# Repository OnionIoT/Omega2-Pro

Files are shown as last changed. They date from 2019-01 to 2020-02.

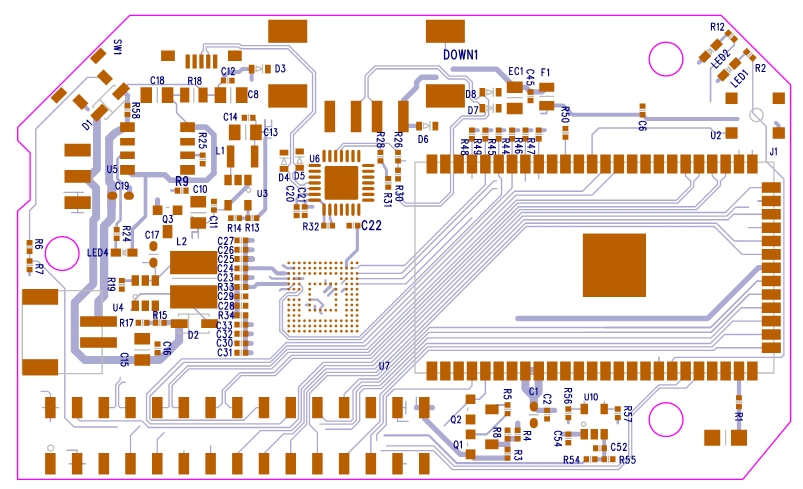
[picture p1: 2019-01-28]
Hardware/R1.2/Omega2-Pro-v1.2-Layout.jpg

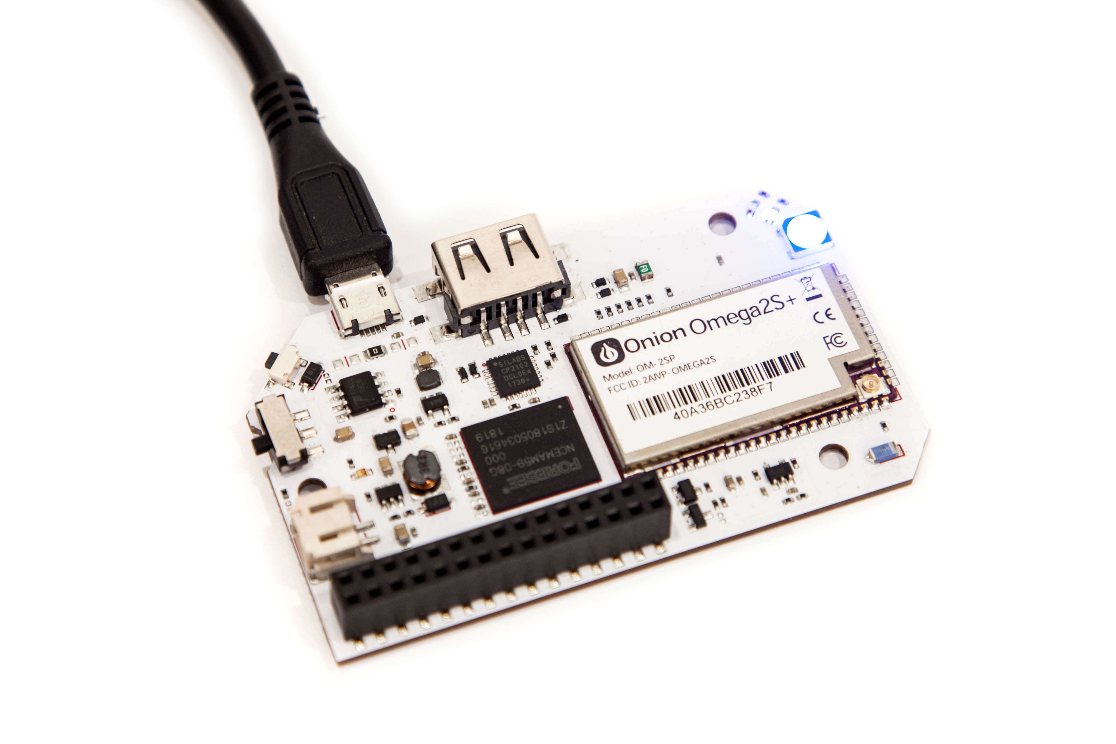
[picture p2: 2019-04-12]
Images/OM-O2PRO-5-led-1.jpg

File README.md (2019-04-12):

# Omega2-Pro
Onion Omega2 Pro IoT Computer

## Getting Started

Get your Omega2 Pro up and running by following the [Omega2 Pro getting started guide](https://onion.io/omega2-pro-get-started/). It also features details on [using your Omega2 Pro](https://onion.io/omega2-pro-get-started/#usingtheomega2pro).

## Images

The [Images](./Images) directory holds official photos of the Omega2 Pro. Credit goes to the team at [Crowd Supply](https://www.crowdsupply.com/).

## Hardware

Schematics and layout images are available for the Omega2 Pro

* R1.2
    * Date: Nov 26, 2018
    * Changes:
        * Small adjustment for power supply circuit

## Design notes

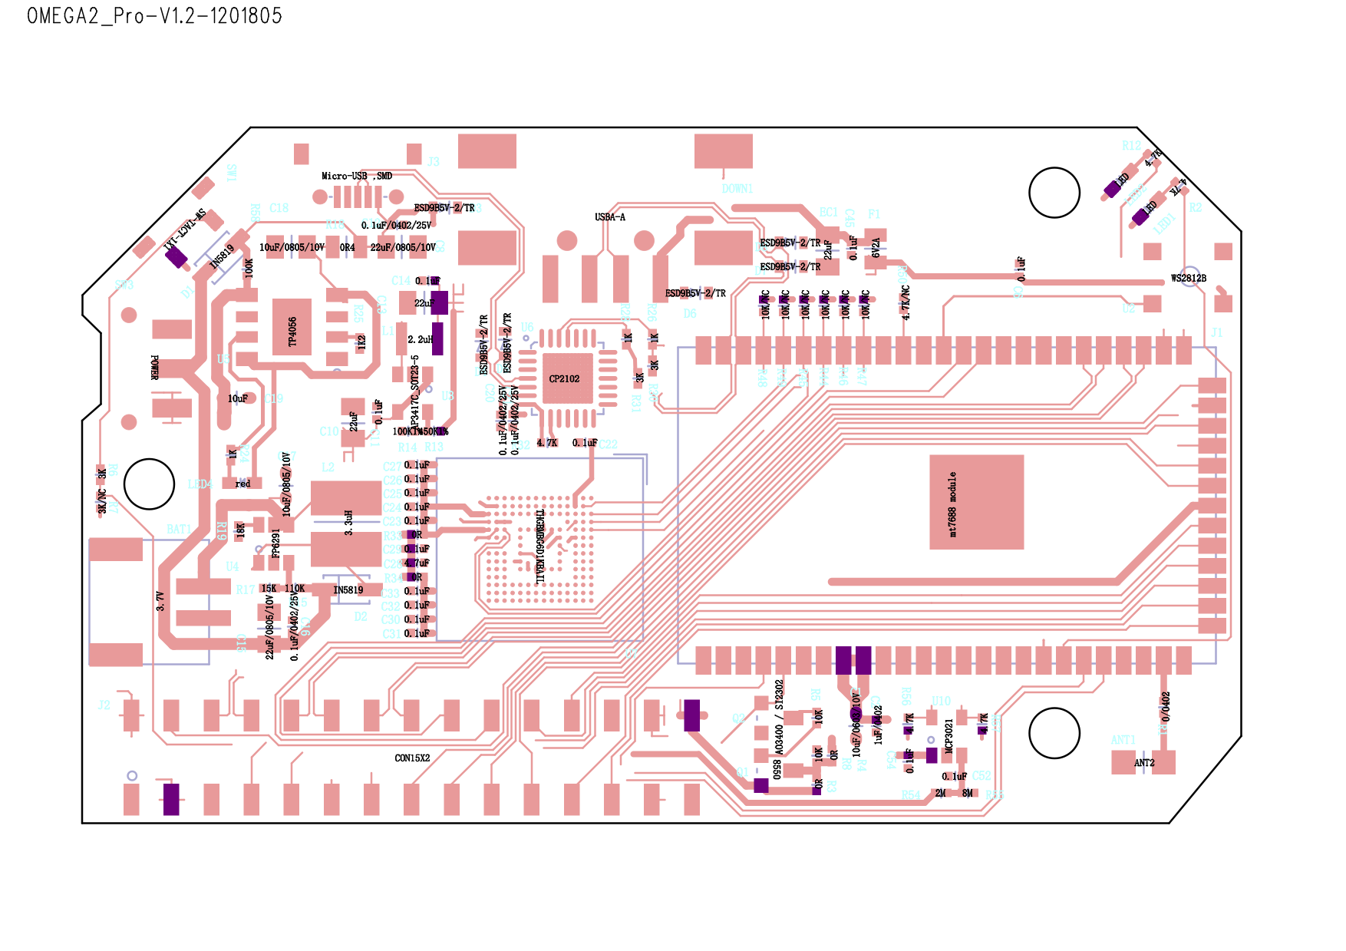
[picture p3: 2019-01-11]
Hardware/R1.1/Omega2-Pro-Layout.png

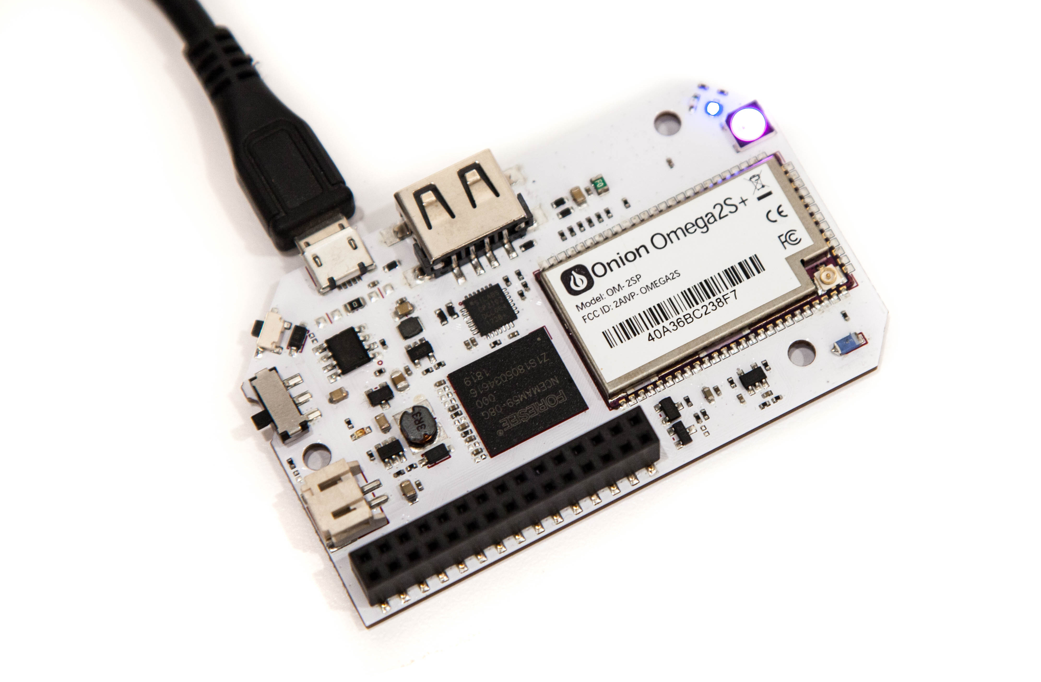
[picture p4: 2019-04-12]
Images/OM-O2PRO-5-led-3.jpg

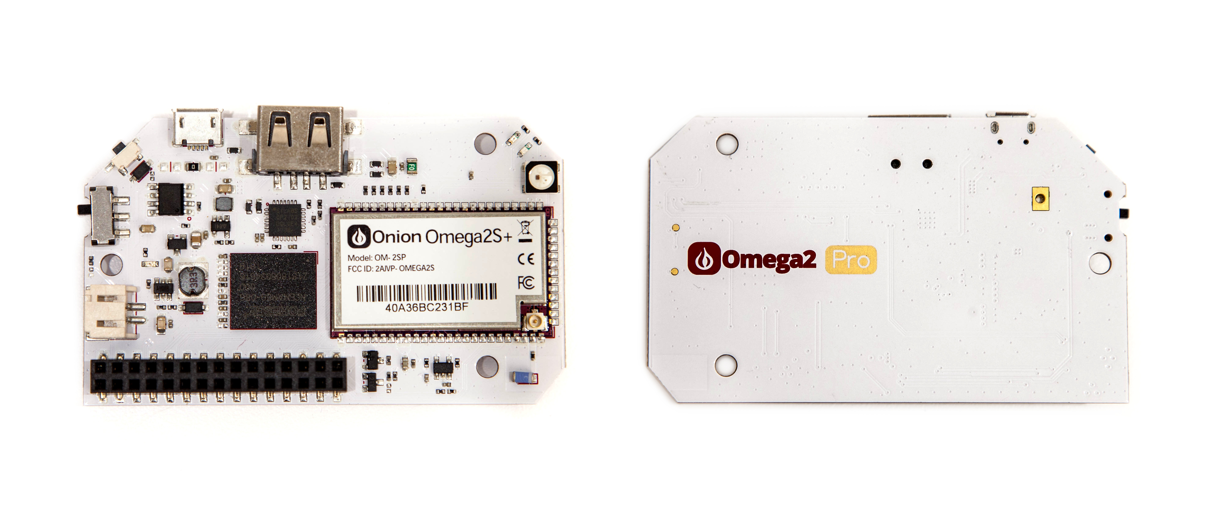
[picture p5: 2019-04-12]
Images/OM-O2PRO-3-side-by-side.jpg

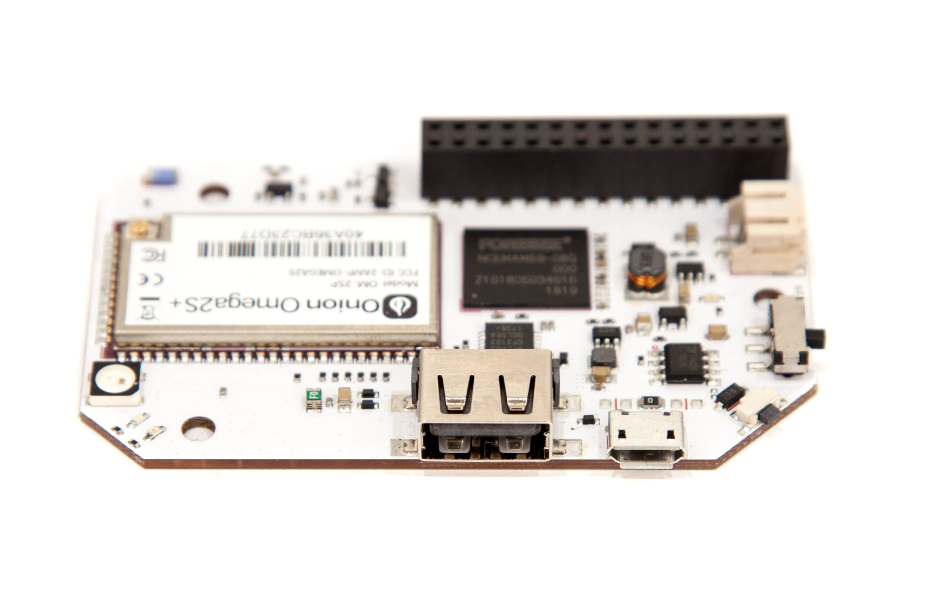
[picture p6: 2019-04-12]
Images/OM-O2PRO-2-side-1.jpg

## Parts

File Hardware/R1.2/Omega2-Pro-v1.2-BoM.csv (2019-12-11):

Index | Name | Qty | Decal | Value
1 | ANT1 | 1 | R1206 | RFANT3216120A5T
2 | BAT1 | 1 | PH_CON2-SMT | PH_CON2-SMT 2.0mm
3 | C1 | 1 | C0603 | 10uF/0603/10V
4 | C2 | 1 | C0402 | 1uF/0402
5 | C6,C11,C14,C22,C23,C27,C30,C33,C45,C52,C54 | 11 | C0402 | 0.1uF
6 | C15 | 1 | C1206 A type 3516 bile capacitor | 68uF 6.3V
 | C10 | 1 | C0805 | 47uF/0805/10V
7 | C12,C16,C20,C21 | 4 | C0402 | 0.1uF/0402/10V
8 | C17,C19,C13,EC1 | 5 | C0805 | 10uF/0805/10V
9 | C28 | 1 | C0402 | 4.7uF
10 | D1,D2 | 2 | SOD-123 | IN5819
11 | D3,D4,D5,D6,D7,D8 | 6 | SOD-523 | ESD5B5.0S
12 | DOWN1 | 1 | USB10/SMT | USB AF short body 10.0 full paste thickness 6.3 with straight edges
13 | F1 | 1 | R0805 | 6V1A
14 | J1 | 1 | Omega2SP | Omega2SP
15 | J2 | 1 | HEADER_2X15 | KONSON row female 2.54 * 7.1 2 * 15P SMT
16 | J3 | 1 | MICRO-USB-5PIN_1 | Micro 5.9 pitch USB socket
17 | L1 | 1 | IND-2520 current 1.2A or above | 2.2uH
18 | L2 | 1 | CD54 | 3.3uH
19 | LED1 | 1 | LED-0603 | LED-0603 Blue
20 | LED2 | 1 | LED-0603 | LED-0603 Orange
21 | LED4 | 1 | LED-0603 | LED-0603 Green
22 | Q1 | 1 | SOT23 | 8550
23 | Q2 | 1 | SOT23-2 | AO3400 / SI2302
24 | Q3 | 1 | SOT23 | AO3401
25 | R26 | 1 | R0402 | 2K
26 | R9,R2_R12,R32,R56,R57,R50,R24 | 8 | R0402 | 4.7K
27 | R1,R4,R33,R34 | 5 | R0402 | 0R
28 | R6,R30,R31 | 3 | R0402 | 3K
29 | R13 | 1 | R0402 | 450K1%
30 | R14 | 1 | R0402 | 100K1%
31 | R15 | 1 | R0402 | 110K
32 | R17 | 1 | R0402 | 15K
33 | R18 | 1 | R0805 | 0R
34 | R19 | 1 | R0402 | 18K
35 | R28 | 2 | R0402 | 1K
36 | R25 | 1 | R0402 | 1K2
37 | R44,R45,R46,R47,R48,R49,R5,R8 | 8 | R0402 | 10K
38 | R54 | 1 | R0402 | 2M
39 | R55 | 1 | R0402 | 8.2M
41 | SW1 | 1 | TACTILE_SWITCH_4 | SW-TACT-1X1 button
42 | SW3 | 1 | SLIDE_SWITCH_5 | POWER switch
43 | U2 | 1 | LED-PAD-4PIN | WS2812B
44 | U3 | 1 | SOT23-5 | AP3417C_SOT23-5
45 | U4 | 1 | SOT23-6 | FP6291
46 | U5 | 1 | SOP8-1_27 | TP4056 1A
47 | U6 | 1 | QFN28_6X6 | CP2102-GMR
48 | U7 | 1 | BGA153/SMD/P0.5/11.5*13mm 8G | eMMC5.1 8GB | Kinston EMMC08G-T227-A01, Sandisk SDINBDG4-8G, FORESEE NCEMAM59-08G
49 | U10 | 1 | SOT23-5 | MCP3021A5T
NC
1 | R7 | 1 | R0402 | 3K/NC
2 | C24,C25,C26,C31,C32,C29, | 6 | C0402 | 0.1uF
3 | R3 | 1 | R0402 | 0R
4 | C8,C18 | 2 | C0805 | 10uf
5 | R58 | 1 | R0402 | 100K

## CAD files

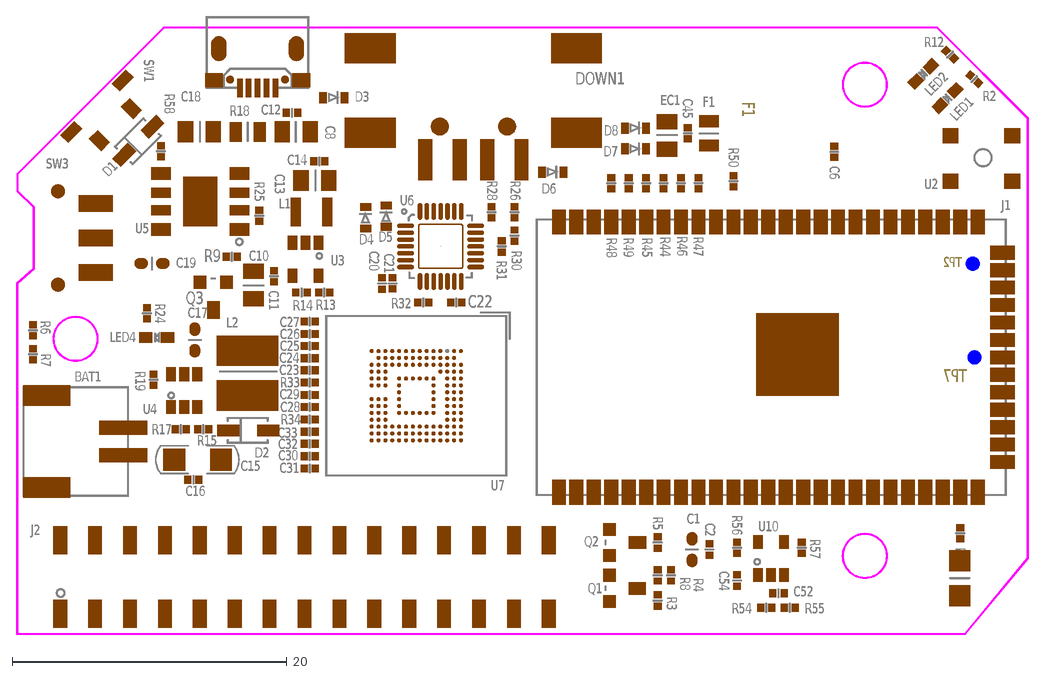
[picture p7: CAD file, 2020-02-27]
Hardware/R1.2/Omega2-Pro.dxf
BAT1
R19
LED4
R9
R55
R54
C19
U7
R6
R7
C22
C11
C12
C14
C16
C2
C20
C21
C23
C24
C25
C26
C27
C28
C29
C30
C31
C32
C33
C45
C52
C54
C6
C1
C17
C10
C13
C18
C8
EC1
L2
J2
L1
LED1
LED2
U2
R1
R12
R13
R14
R15
R17
R2
R24
R25
R26
R28
R3
R30
R31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

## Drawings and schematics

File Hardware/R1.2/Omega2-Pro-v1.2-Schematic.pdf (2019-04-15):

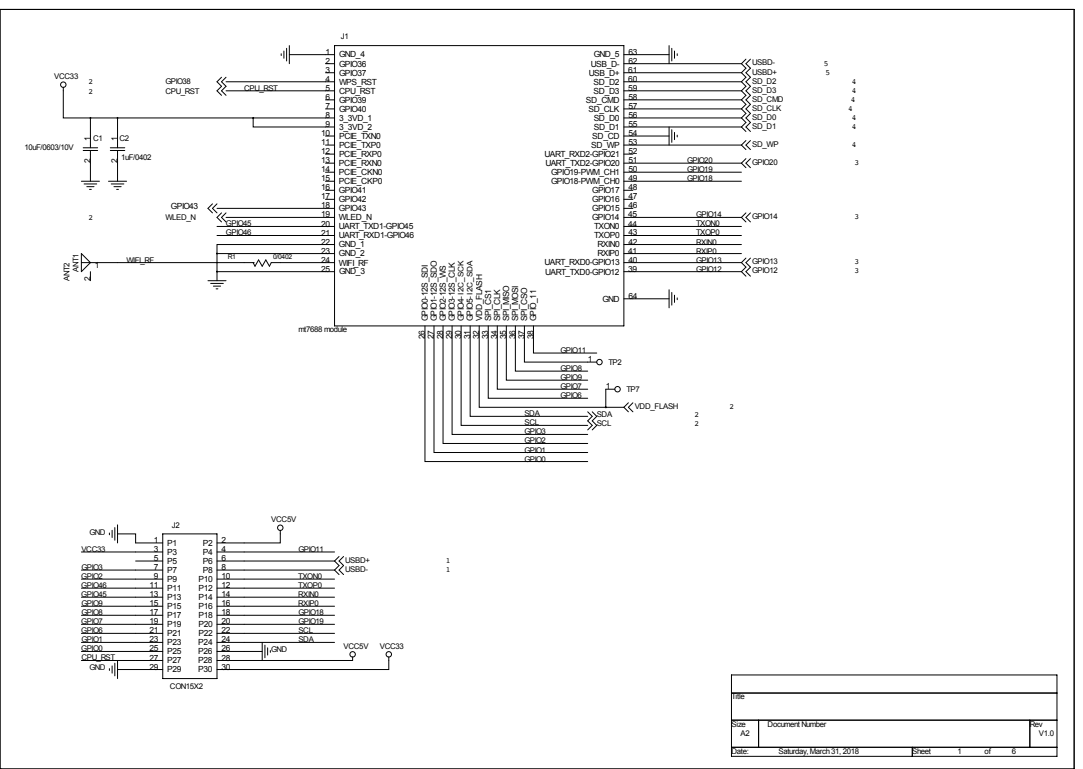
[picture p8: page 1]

Size A2 | Document Number | Rev V1.0

Date: Saturday, March31, 2018 | Sheet 1 of

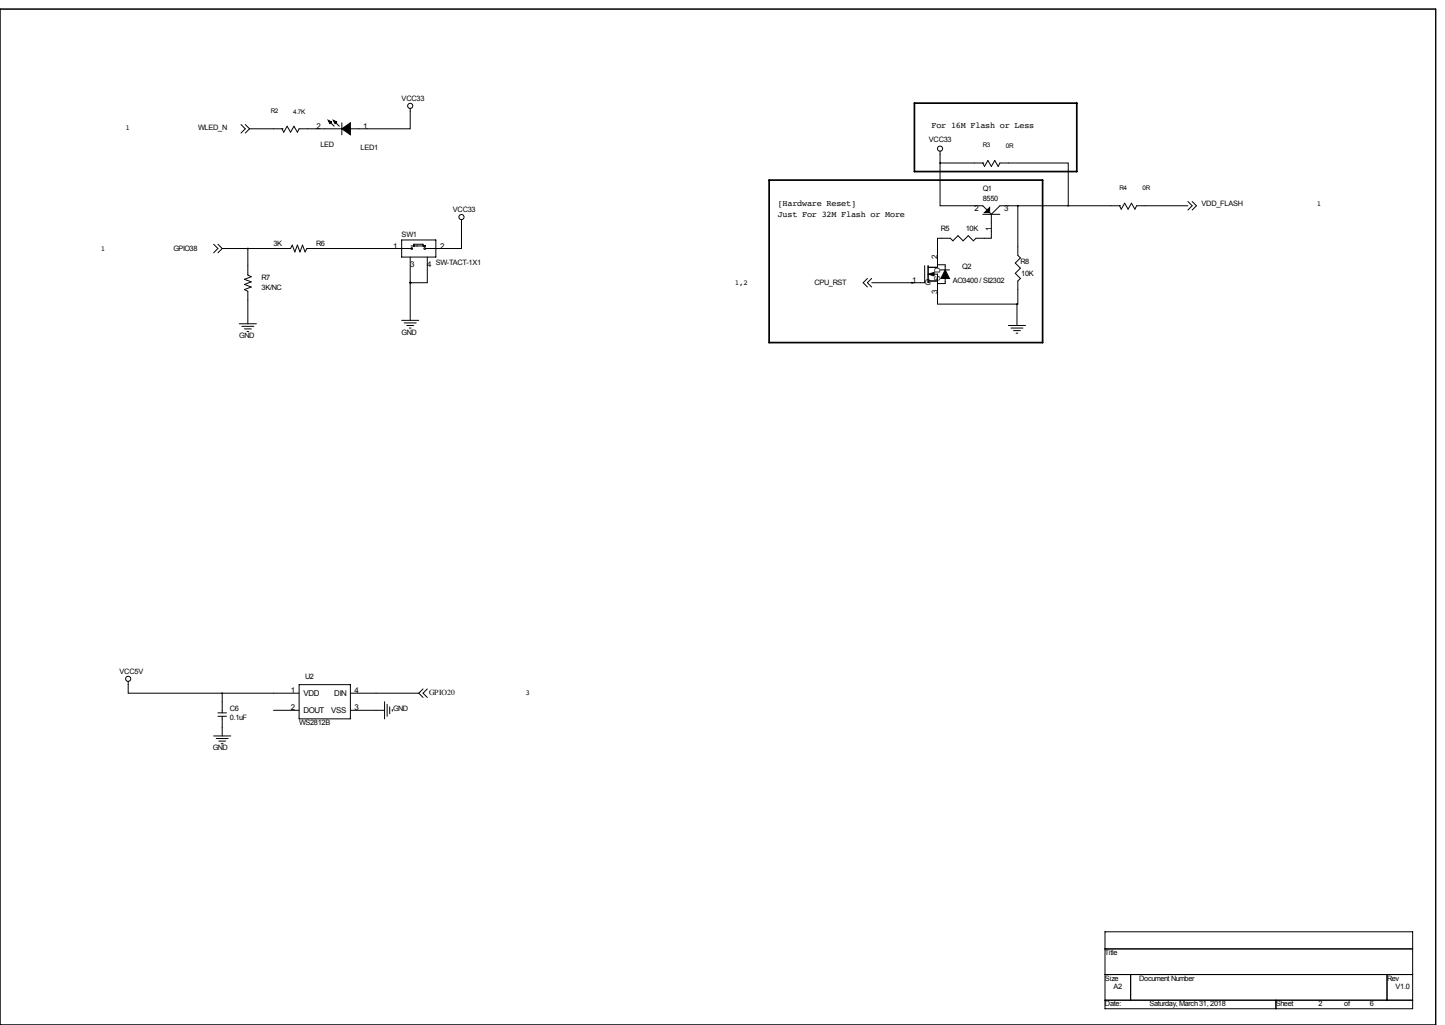
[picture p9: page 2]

[Hardware Reset]
Just For 32M Flash or More

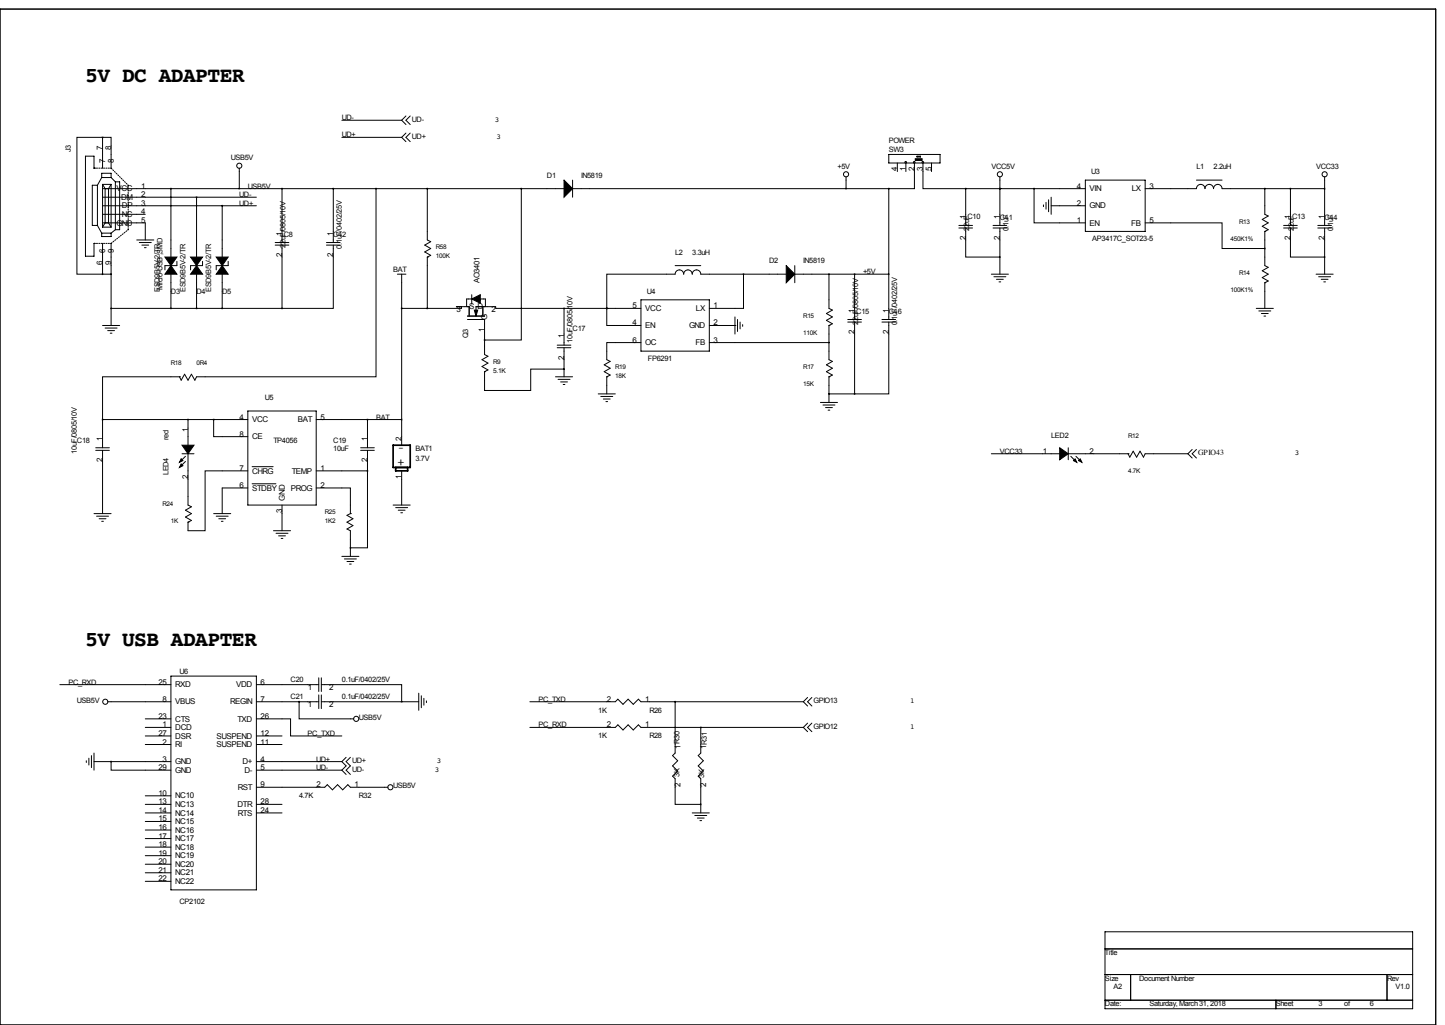
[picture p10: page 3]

DM 2 | UD- | | L2 3.3uH
DP 3 | | UD+
NC 4

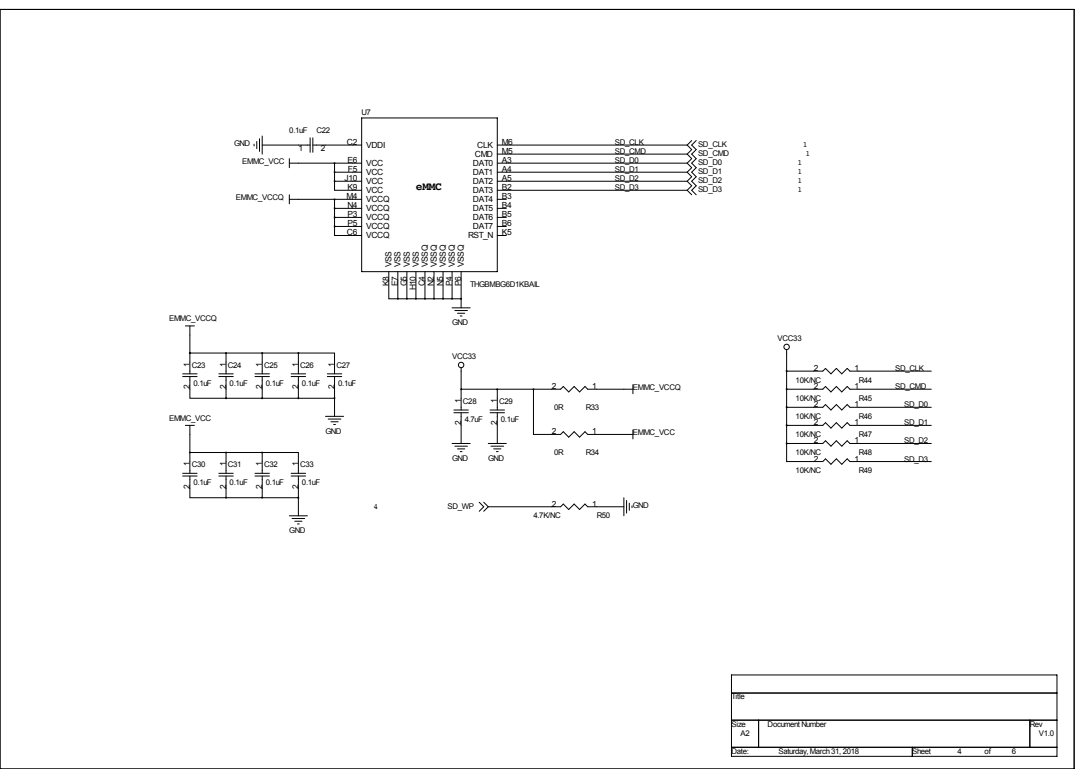
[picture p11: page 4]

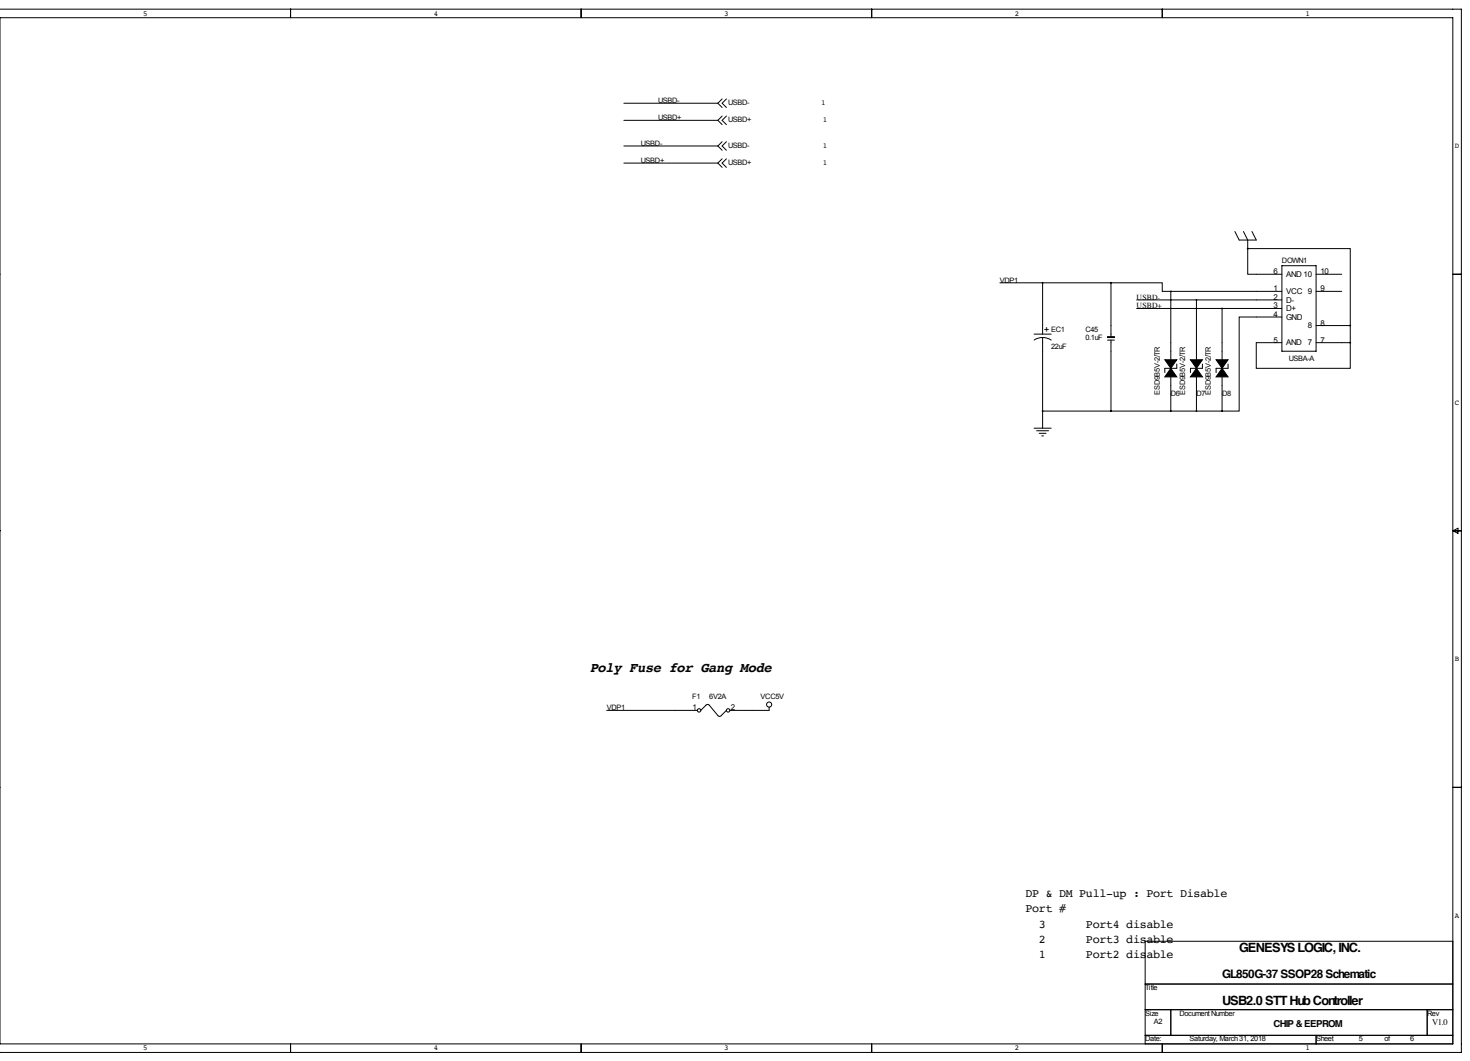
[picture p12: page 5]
GL850G-37 SSOP28 Schematic; Port4 disable; Port3 disable; Port2 disable; ESD9B5V-2/TR; AND; VCC; GND; DOWN1; USBA-A; VCC5V; USBD-; USBD+; VDP1

Poly Fuse for Gang Mode

DP & DM Pull-up : Port Disable
Port #

GENESYS LOGIC, INC.

USB2.0 STT Hub Controller

CHIP & EEPROM

Date: | Sheet 5 of 6

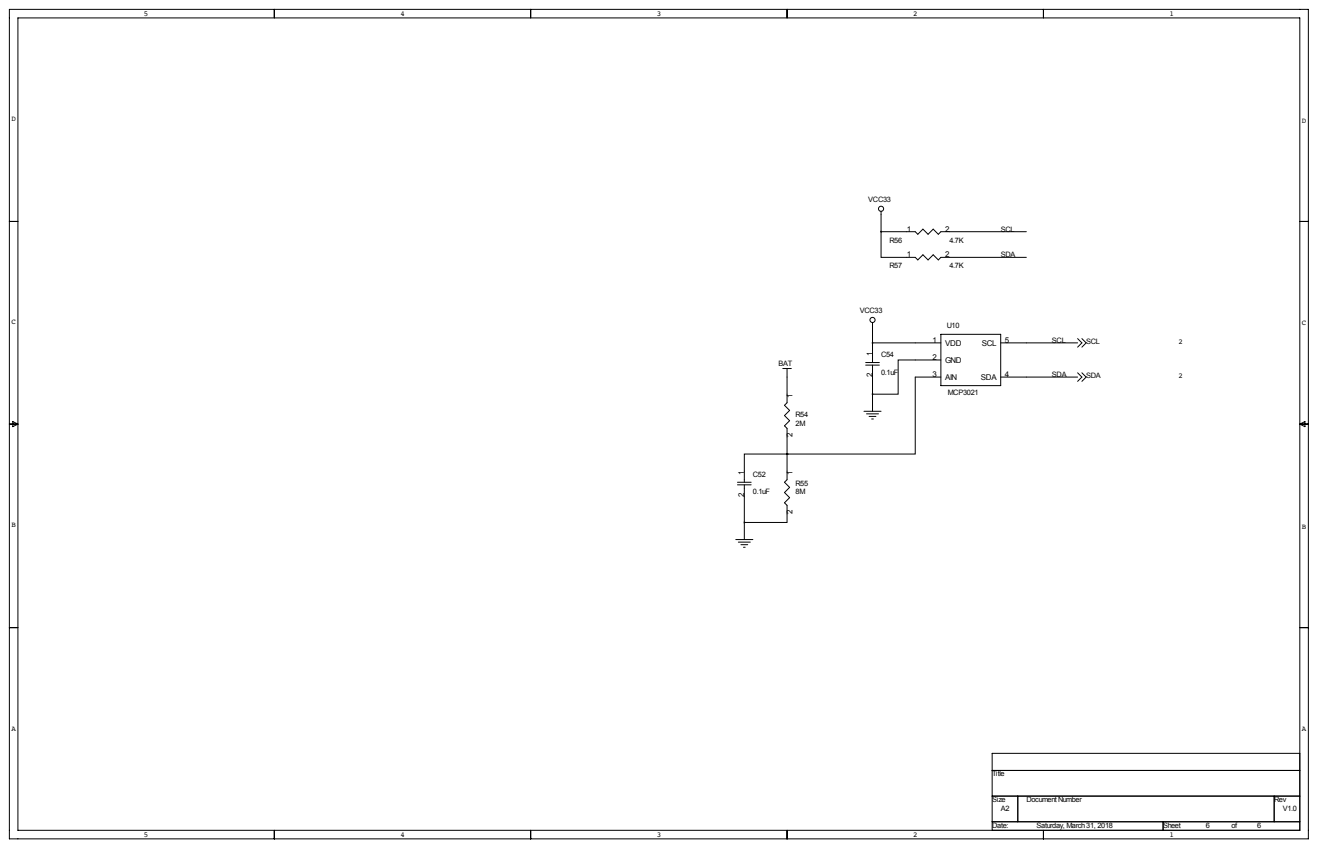
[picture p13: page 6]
Date:; Sheet; Title; VDD; GND; AIN; 4 SDA; 5 SCL; MCP3021 1 2 R54; VCC33; BAT; SDA; SCL

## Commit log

2019-04-15 fixed typo on I2C pins
2019-04-15 proper fix for I2C pins typo on schematic
2019-12-11 added omega2 pro bom
    [Omega2-Pro-v1.2-BoM.csv]
2019-12-11 small fix for bom
    [Omega2-Pro-v1.2-BoM.csv]
2020-02-27 added dxf measurement file
    [Omega2-Pro.dxf]
